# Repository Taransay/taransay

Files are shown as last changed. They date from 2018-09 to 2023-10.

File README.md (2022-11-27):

# Taransay home monitoring hardware and firmware
This is a series of wireless (433 MHz) electricity, gas, temperature and humidity monitors, electricity switches
and RGB(W) controllers and base station, with interoperability with [Home Assistant](https://www.home-assistant.io/). It uses low cost RF modules from HopeRF for intercommunication, avoiding the security
implications of having several seldomly-updated WiFi modules on your home network. The range is also
far greater.

The hardware and firmware designs are loosely based on those of the [emonTx](https://github.com/openenergymonitor/emontx3), [emonTH](https://github.com/openenergymonitor/emonth2) (both [OpenEnergyMonitor](http://openenergymonitor.com/)) and [Moteino](https://lowpowerlab.com/guide/moteino/) (LowPowerLab).

The firmware is designed to talk to Home Assistant via the Taransay base station, which is a small
transceiver that plugs into a Raspberry Pi or similar and talks to an instance of [Taransay
Data Forwarder](https://github.com/Taransay/taransayhub) over serial. This way, you just need to
keep your Raspberry Pi updated and not several distributed devices.

## Status
The hardware and firmware all works, though there are few instructions for getting it all to work,
so if you happen to want to use any of this it's best to get in touch.

## Credits
Sean Leavey <https://github.com/SeanDS>

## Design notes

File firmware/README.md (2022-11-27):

Taransay firmware
=================

Programming ATmega328P
----------------------

Using `avr-gcc` and `avrdude`. Alternative is to install Arduino IDE.

Requirements for Ubuntu:

```bash
sudo apt install gcc-avr binutils-avr gdb-avr avr-libc avrdude
```

Programmer might require special `udev` rules on Ubuntu. For instance, here is a `udev` entry for
the Atmel ICE, which should go in `/etc/udev/rules.d/99-atmelice.rules`:

```
SUBSYSTEM!="usb", ACTION!="add", GOTO="atmelice_end"

# Atmel Corp. Atmel ICE
ATTR{idVendor}=="03eb", ATTR{idProduct}=="2141", MODE="660", GROUP="dialout"

LABEL="atmelice_end"
```

After creating, restart `udev` with `sudo service udev restart`. Also ensure your user is part of
the `dialout` group.

Set fuses
---------

```
avrdude -p atmega328p -P usb -c atmelice_isp -U lfuse:w:0xff:m -U hfuse:w:0xd9:m -U efuse:w:0xff:m
```

Need to set those fuses otherwise weird serial outputs occur with characters etc.

Programming with ISP
--------------------

6-pin ISP header should be oriented with notch facing towards edge of board.

UART header mapping (starting from edge of board): GND, RX on board / TX on converter, TX on board /
RX on converter, DTR, 3V3

```
avrdude -p atmega328p -P usb -c atmelice_isp -U flash:w:taransay_X.ino.eightanaloginputs.hex
```

View device serial
------------------

```
minicom -b 115200 -D /dev/ttyUSB0
```

Writing messages to serial device
---------------------------------

```
echo -en 'hello\n' > /dev/ttyUSB0
```

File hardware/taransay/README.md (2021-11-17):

Taransay
========

Arduino-compatible RF transceiver board.

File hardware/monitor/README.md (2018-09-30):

Changes from emonTx V3.4 / emonTH V2.0
======================================

- Various component tweaks: different models, mainly
- Removed 3/4 current sensors
- Added Si7020/Si7021 temperature/humidity probe from emonTH V2
  - Reused ADC4 and ADC5 for SDA/SCL I2C bus to communicate with Si7020
  - Changed DS18B20 data pin from D5 to PC2 (ADC2) amd power pin from ADC5 to PC3 (ADC3)
- Removed ESP UART socket
- Explicitly implemented RFM69CW instead of (pin compatible) RFM12B
- Split pulse and temperature monitor ports into separate ports
  - Made PD4 the pulse power pin
- Changed pulse and temperature sockets from RJ45 to Molex Nano-Fit
- Removed AC-AC input
- Removed USB socket

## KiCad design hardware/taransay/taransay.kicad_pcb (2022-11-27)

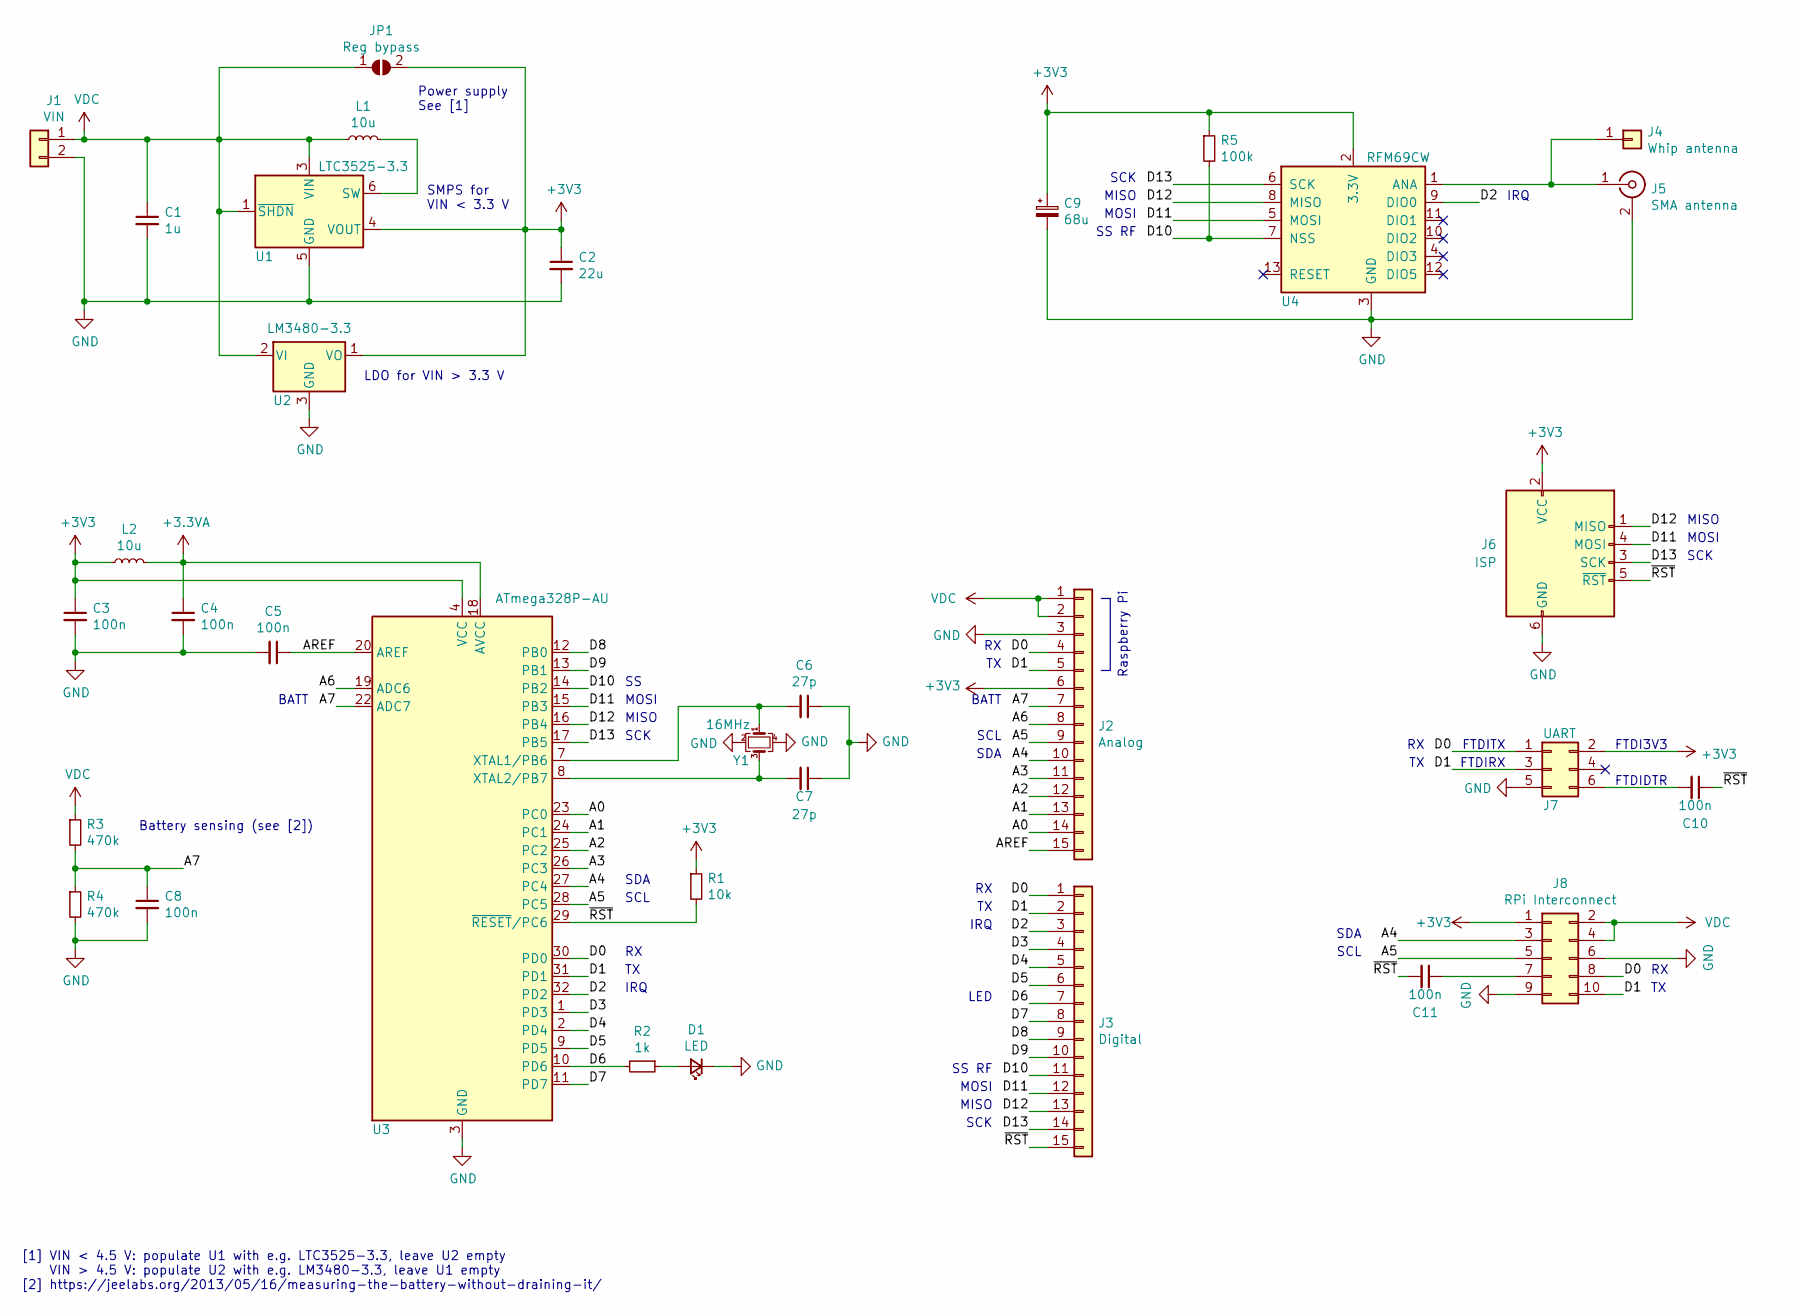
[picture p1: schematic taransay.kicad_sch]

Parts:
C1: 1u; C_0805_2012Metric; MPN1 C0805C105K4RACTU
C2: 22u; C_0805_2012Metric; MPN1 C0805C220J5GACTU
C3, C4, C5, C8, C10, C11: 100n; C_0805_2012Metric
C6, C7: 27p; C_0603_1608Metric
C9: 68u; CP_Radial_D6.3mm_P2.50mm
D1: LED; LED_0805_2012Metric_Pad1.15x1.40mm_HandSolder; MPN1 LG R971
J1: VIN; SolderWire-0.75sqmm_1x02_P4.8mm_D1.25mm_OD2.3mm
J2: Analog; PinSocket_1x15_P2.54mm_Vertical
J3: Digital; PinSocket_1x15_P2.54mm_Vertical
J4: Whip antenna; SolderWire-0.25sqmm_1x01_D0.65mm_OD1.7mm
J5: SMA antenna; SMA_Molex_73251-1153_EdgeMount_Horizontal; MPN1 73251-1150
J6: ISP; PinHeader_2x03_P2.54mm_Vertical; MPN1 251-8137
J7: UART; PinHeader_2x03_P2.54mm_Vertical; MPN1 251-8121
J8: RPi Interconnect; PinSocket_2x05_P2.54mm_Vertical; MPN1 215307-5
JP1: Reg bypass; SolderJumper-2_P1.3mm_Open_RoundedPad1.0x1.5mm
L1, L2: 10u; L_1210_3225Metric_Pad1.42x2.65mm_HandSolder; MPN1 LQH32CN100K53L
R1: 10k; R_0805_2012Metric
R2: 1k; R_0805_2012Metric
R3, R4: 470k; R_0805_2012Metric
R5: 100k; R_0805_2012Metric
U1: LTC3525-3.3; SOT-363_SC-70-6; MPN1 LTC3525ESC6-3.3#TRMPBF
U2: LM3480-3.3; SOT-23
U3: ATmega328P-AU; TQFP-32_7x7mm_P0.8mm
U4: RFM69CW; HOPERF_RFM69CW
Y1: 16MHz; Crystal_SMD_Abracon_ABM8G-4Pin_3.2x2.5mm; MPN1 ABM8-16.000MHZ-7-1-U-T

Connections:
+3.3VA: C4.1, L2.2, U3.18 (AVCC)
+3V3: C2.1, C3.1, C9.1, J2.6, J6.2 (VCC), J7.2, J8.1, JP1.2 (B), L2.1, R1.1, R5.1, U1.4 (VOUT), U2.1 (VO), U3.4 (VCC), U3.6 (VCC), U4.2 (3.3V)
/A0: J2.14, U3.23 (PC0)
/A1: J2.13, U3.24 (PC1)
/A2: J2.12, U3.25 (PC2)
/A3: J2.11, U3.26 (PC3)
/A4: J2.10, J8.3, U3.27 (PC4)
/A5: J2.9, J8.5, U3.28 (PC5)
/A6: J2.8, U3.19 (ADC6)
/A7: C8.1, J2.7, R3.2, R4.1, U3.22 (ADC7)
/AREF: C5.1, J2.15, U3.20 (AREF)
/D0: J2.4, J3.1, J7.1, J8.8, U3.30 (PD0)
/D1: J2.5, J3.2, J7.3, J8.10, U3.31 (PD1)
/D2: J3.3, U3.32 (PD2), U4.9 (DIO0)
/D3: J3.4, U3.1 (PD3)
/D4: J3.5, U3.2 (PD4)
/D5: J3.6, U3.9 (PD5)
/D6: J3.7, R2.2, U3.10 (PD6)
/D7: J3.8, U3.11 (PD7)
/D8: J3.9, U3.12 (PB0)
/D9: J3.10, U3.13 (PB1)
/D10: J3.11, R5.2, U3.14 (PB2), U4.7 (NSS)
/D11: J3.12, J6.4 (MOSI), U3.15 (PB3), U4.5 (MOSI)
/D12: J3.13, J6.1 (MISO), U3.16 (PB4), U4.8 (MISO)
/D13: J3.14, J6.3 (SCK), U3.17 (PB5), U4.6 (SCK)
/~RST: C10.1, C11.2, J3.15, J6.5 (~RST), R1.2, U3.29 (~RESET/PC6)
GND: C1.2, C2.2, C3.2, C4.2, C5.2, C6.1, C7.1, C8.2, C9.2, D1.1 (K), J1.2, J2.3, J5.2 (Ext), J6.6 (GND), J7.5, J8.6, J8.9, R4.2, U1.2 (GND), U1.5 (GND), U2.3 (GND), U3.3 (GND), U3.5 (GND), U3.21 (GND), U4.3 (GND), U4.14 (GND), Y1.2, Y1.4
unnamed: C6.2, U3.7 (XTAL1/PB6), Y1.1
unnamed: C7.2, U3.8 (XTAL2/PB7), Y1.3
unnamed: C10.2, J7.6
unnamed: C11.1, J8.7
unnamed: D1.2 (A), R2.1
unnamed: J4.1, J5.1 (In), U4.1 (ANA)
unnamed: L1.2, U1.6 (SW)
VDC: C1.1, J1.1, J2.1, J2.2, J8.2, J8.4, JP1.1 (A), L1.1, R3.1, U1.1 (~SHDN), U1.3 (VIN), U2.2 (VI)

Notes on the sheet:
LED
MISO
FTDI3V3
FTDIDTR
IRQ
SCL
SCK
MOSI
BATT
[1] VIN < 4.5 V: populate U1 with e.g. LTC3525-3.3, leave U2 empty VIN > 4.5 V: populate U2 with e.g. LM3480-3.3, leave U1 empty [2] https://jeelabs.org/2013/05/16/measuring-the-battery-without-draining-it/
SDA
LDO for VIN > 3.3 V
FTDITX
Battery sensing (see [2])
FTDIRX
SS RF
SMPS for VIN < 3.3 V
Power supply See [1]
Raspberry Pi

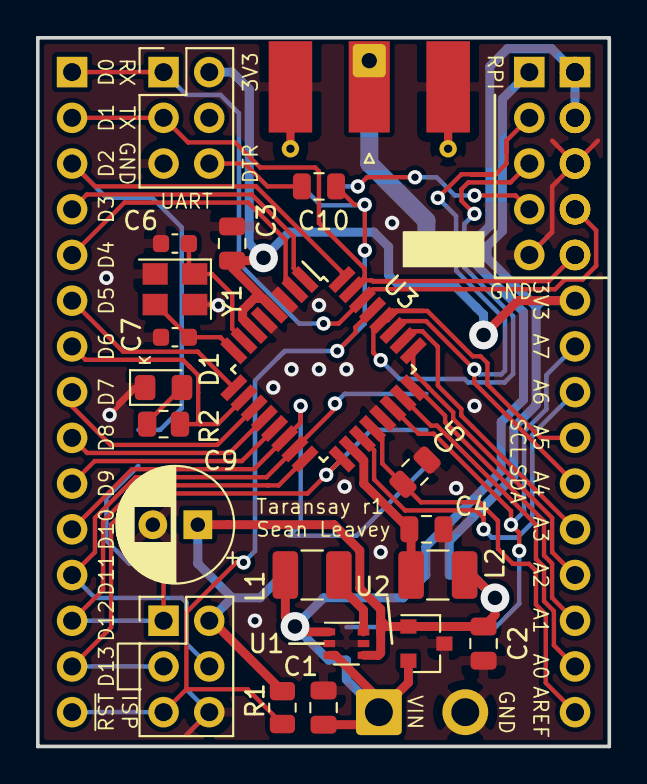
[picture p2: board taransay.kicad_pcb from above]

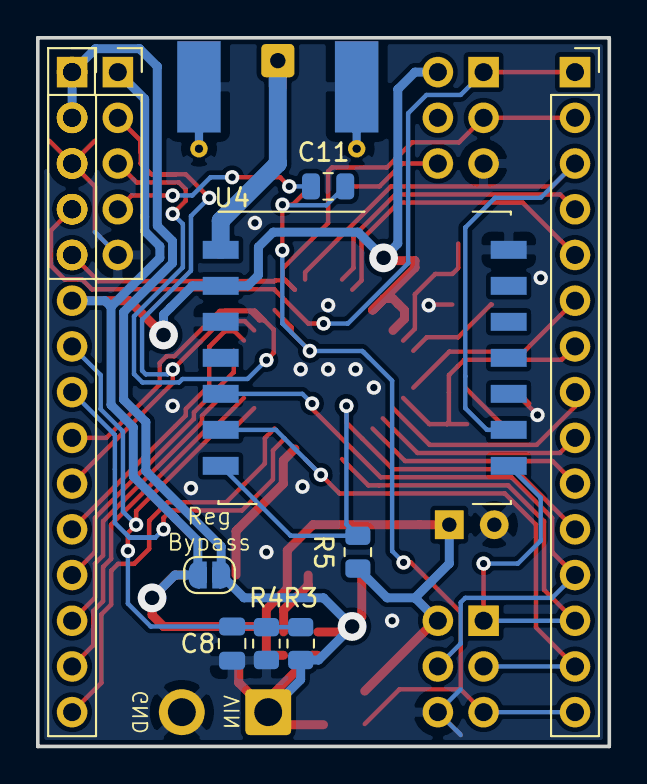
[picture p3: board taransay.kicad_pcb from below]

Board: 2 copper layers, 31.8 x 39.4 mm, 33 parts (10 on the bottom side), 35 nets.

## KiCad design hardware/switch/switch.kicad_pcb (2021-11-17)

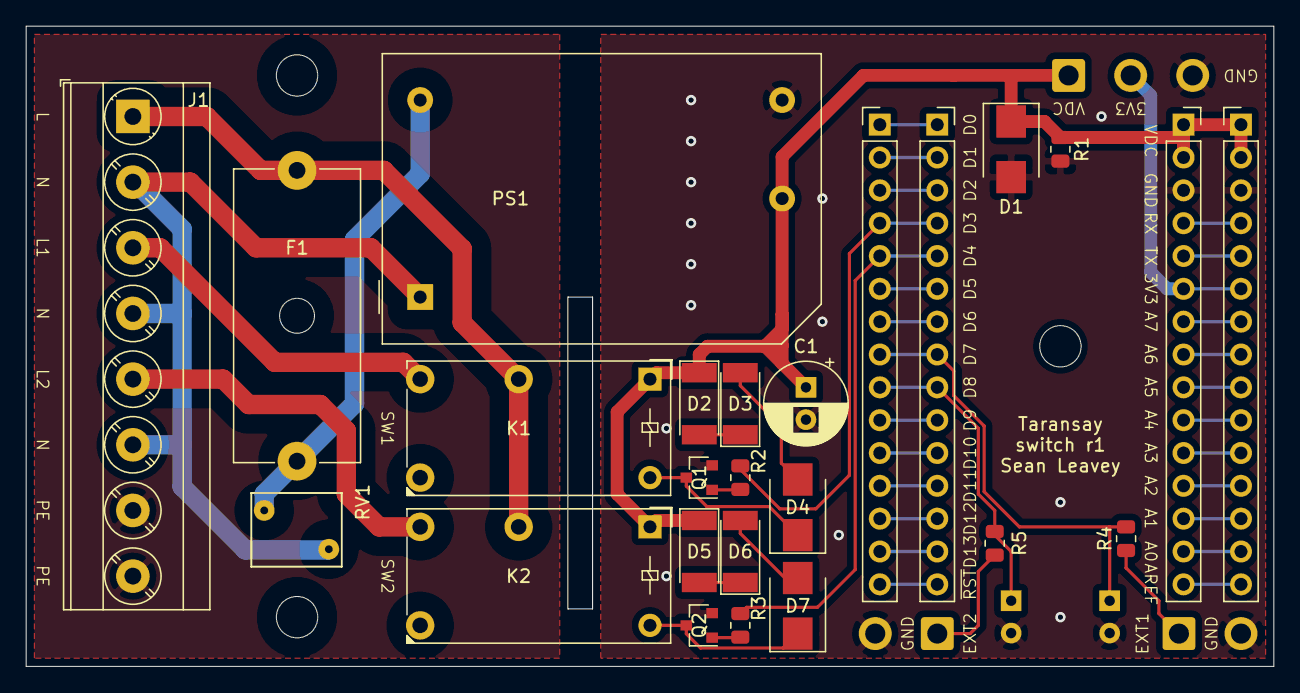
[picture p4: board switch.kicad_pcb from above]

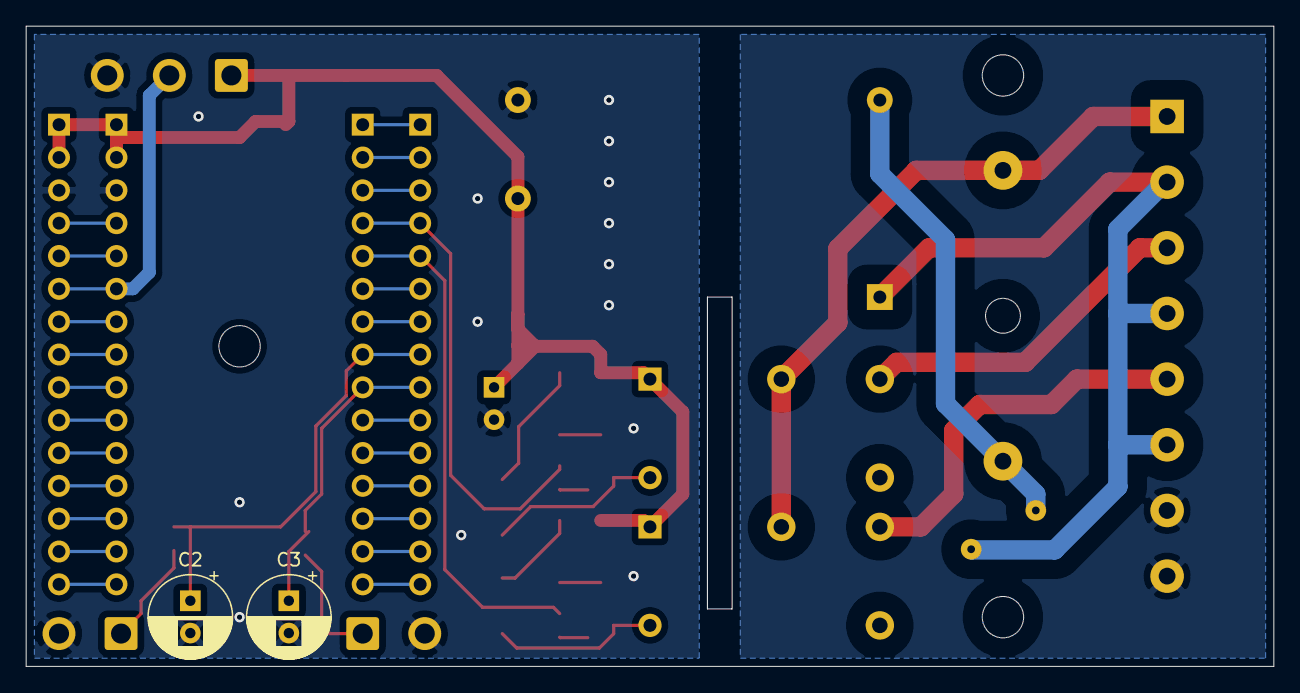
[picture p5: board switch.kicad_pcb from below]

Board: 2 copper layers, 96.5 x 49.5 mm, 33 parts (2 on the bottom side), 43 nets.

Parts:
C1, C2, C3: 68u; CP_Radial_D6.3mm_P2.50mm
D1, D4, D7: SMBJ7.0A; D_SMB
D2, D3, D5, D6: SM4007; D_MELF
F1: Fuse; Fuseholder_Cylinder-5x20mm_Schurter_0031_8201_Horizontal_Op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
H1, H2, H3: MountingHole; MountingHole_3.2mm_M3
J1: Power; TerminalBlock_Phoenix_MKDS-3-8-5.08_1x08_P5.08mm_Horizontal
J2: DC; SolderWire-0.75sqmm_1x03_P4.8mm_D1.25mm_OD2.3mm
J3: External button 1; SolderWire-0.75sqmm_1x02_P4.8mm_D1.25mm_OD2.3mm
J4: External button 2; SolderWire-0.75sqmm_1x02_P4.8mm_D1.25mm_OD2.3mm
J5: Analog; PinHeader_1x15_P2.54mm_Vertical
J6: Digital; PinHeader_1x15_P2.54mm_Vertical
J7: Analog breakout; PinSocket_1x15_P2.54mm_Vertical
J8: Digital breakout; PinSocket_1x15_P2.54mm_Vertical
K1, K2: FINDER-32.21-x000; Relay_SPDT_Finder_32.21-x000
PS1: RAC01-05SGB; Converter_ACDC_RECOM_RAC01-xxSGB_THT
Q1, Q2: MMBT2222AL; SOT-23
R1: NP; R_0805_2012Metric
R2, R3: 3k01; R_0805_2012Metric
R4, R5: 1k; R_0805_2012Metric
RV1: Varistor; RV_Disc_D7mm_W5.7mm_P5mm

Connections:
+3V3: J2.2, J5.6, J7.6
/A0: J5.14, J7.14
/A1: J5.13, J7.13
/A2: J5.12, J7.12
/A3: J5.11, J7.11
/A4: J5.10, J7.10
/A5: J5.9, J7.9
/A6: J5.8, J7.8
/A7: J5.7, J7.7
/AREF: J5.15, J7.15
/D0: J5.4, J6.1, J7.4, J8.1
/D1: J5.5, J6.2, J7.5, J8.2
/D2: J6.3, J8.3
/D3: J6.4, J8.4, R2.2
/D4: J6.5, J8.5, R3.2
/D5: J6.6, J8.6
/D6: J6.7, J8.7
/D7: C2.1, J6.8, J8.8, R4.2
/D8: C3.1, J6.9, J8.9, R5.2
/D9: J6.10, J8.10
/D10: J6.11, J8.11
/D11: J6.12, J8.12
/D12: J6.13, J8.13
/D13: J6.14, J8.14
/~RST: J6.15, J8.15
Earth_Protective: J1.7, J1.8
GND: C1.2, C2.2, C3.2, D1.2, J2.3, J3.2, J4.2, J5.3, J7.3, PS1.3, Q1.2, Q2.2, R1.2
unnamed: D2.2, D3.1
unnamed: D3.2, D4.2
unnamed: D4.1, K1.A2, Q1.3
unnamed: D5.2, D6.1
unnamed: D6.2, D7.2
unnamed: D7.1, K2.A2, Q2.3
unnamed: F1.1, PS1.2, RV1.1
unnamed: F1.2, J1.1, K1.11, K2.11
unnamed: J1.2, J1.4, J1.6, PS1.1, RV1.2
unnamed: J1.3, K1.14
unnamed: J1.5, K2.14
unnamed: J3.1, R4.1
unnamed: J4.1, R5.1
unnamed: Q1.1, R2.1
unnamed: Q2.1, R3.1
VDC: C1.1, D1.1, D2.1, D5.1, J2.1, J5.1, J5.2, J7.1, J7.2, K1.A1, K2.A1, PS1.4, R1.1

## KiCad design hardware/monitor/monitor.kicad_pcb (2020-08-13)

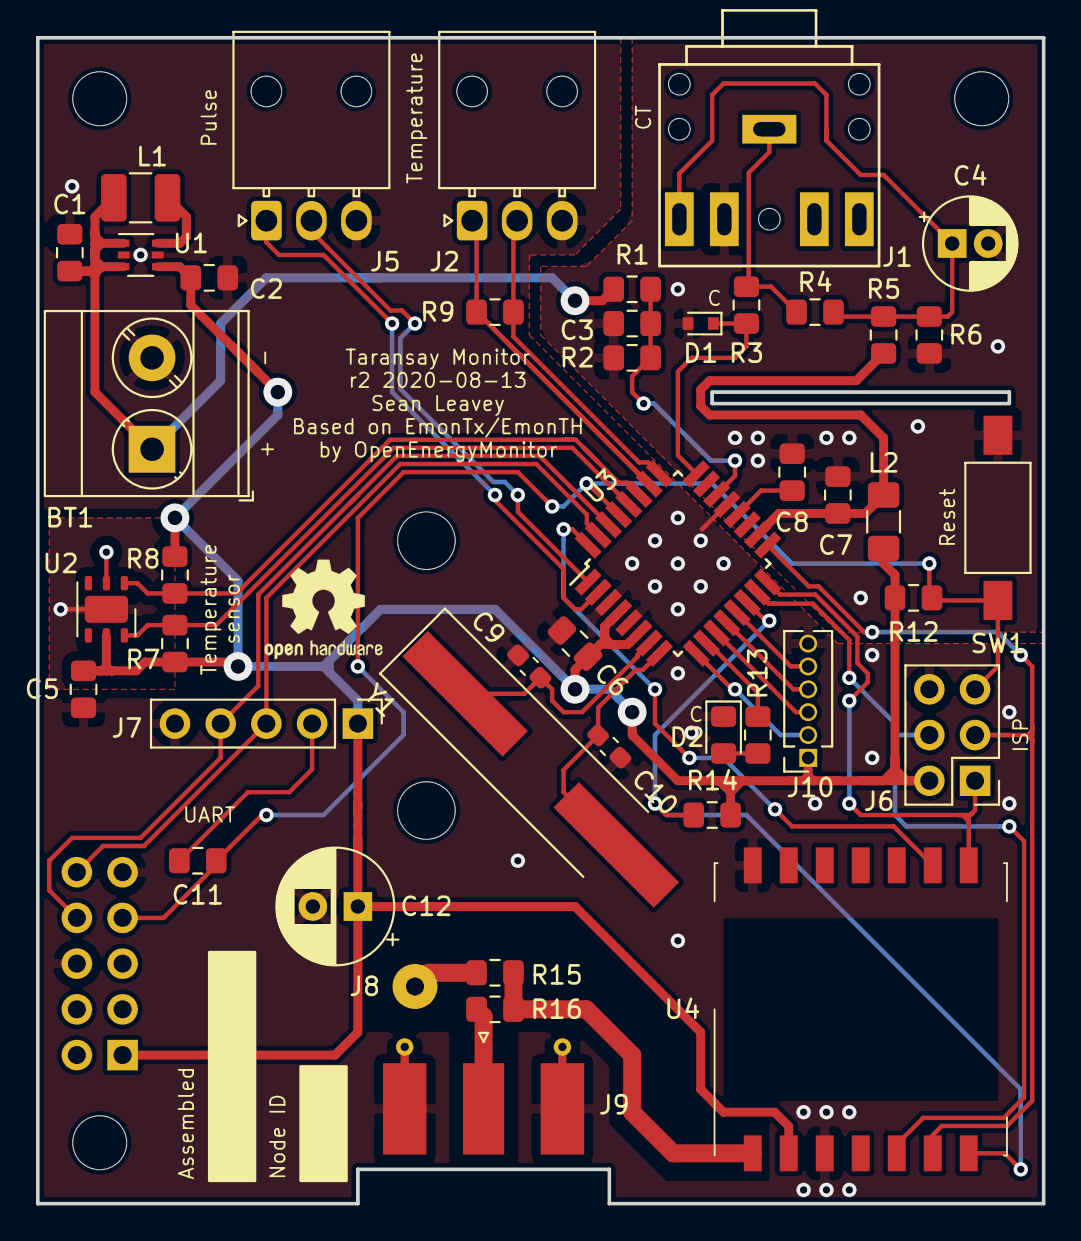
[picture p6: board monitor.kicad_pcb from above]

Board: 2 copper layers, 55.9 x 64.8 mm, 52 parts (1 on the bottom side), 36 nets.

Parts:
BT1: Battery; TerminalBlock_Phoenix_MKDS-3-2-5.08_1x02_P5.08mm_Horizontal
C1: 1u; C_0805_2012Metric_Pad1.15x1.40mm_HandSolder
C2: 22u; C_0805_2012Metric_Pad1.15x1.40mm_HandSolder
C3: NP; C_0805_2012Metric_Pad1.15x1.40mm_HandSolder
C4: 10u; CP_Radial_D5.0mm_P2.00mm
C5, C6, C7, C8, C11: 100n; C_0805_2012Metric_Pad1.15x1.40mm_HandSolder
C9, C10: 26p; C_0603_1608Metric_Pad1.05x0.95mm_HandSolder
C12: 68u; CP_Radial_D6.3mm_P2.50mm
D1: ESD5Z3.3T1G; D_SOD-523
D2: LED; LED_0805_2012Metric_Pad1.15x1.40mm_HandSolder
H1: Mount 1; MountingHole_3mm
H2: Mount 2; MountingHole_3mm
H3: Mount 3; MountingHole_3mm
H5: Battery Mount 1; MountingHole_3.2mm_M3
H6: Battery Mount 2; MountingHole_3.2mm_M3
J1: CT; StereoJack_3.5mm_Switch_Cliff_JY039-5P_Horizontal
J2: T1; Molex_Nano-Fit_105313-xx03_1x03_P2.50mm_Horizontal
J3: RPi Interconnect; PinSocket_2x05_P2.54mm_Vertical
J5: Pulse; Molex_Nano-Fit_105313-xx03_1x03_P2.50mm_Horizontal
J6: ISP; PinHeader_2x03_P2.54mm_Vertical
J7: UART; PinHeader_1x05_P2.54mm_Vertical
J8: Whip antenna; SolderWirePad_1x01_Drill1mm
J9: SMA antenna; SMA_Molex_73251-1153_EdgeMount_Horizontal
J10: Spare; PinSocket_1x06_P1.27mm_Vertical
L1: 10u; L_1210_3225Metric_Pad1.42x2.65mm_HandSolder
L2: 10u; L_1206_3216Metric_Pad1.42x1.75mm_HandSolder
LOGO1: Logo; OSHW-Logo2_7.3x6mm_SilkScreen
R1, R2: 470k; R_0805_2012Metric_Pad1.15x1.40mm_HandSolder
R3, R13: 1k; R_0805_2012Metric_Pad1.15x1.40mm_HandSolder
R4: 22R/0.1%; R_0805_2012Metric_Pad1.15x1.40mm_HandSolder
R5, R6: 470k/0.1%; R_0805_2012Metric_Pad1.15x1.40mm_HandSolder
R7, R8, R9: 4k7; R_0805_2012Metric_Pad1.15x1.40mm_HandSolder
R12: 10k; R_0805_2012Metric_Pad1.15x1.40mm_HandSolder
R14: 100k; R_0805_2012Metric_Pad1.15x1.40mm_HandSolder
R15, R16: 0R; R_0805_2012Metric_Pad1.15x1.40mm_HandSolder
SW1: Reset; SW_SPST_FSMSM
U1: LTC3525-3.3; SOT-363_SC-70-6
U2: Si7020-A20; DFN-6-1EP_3x3mm_P1mm_EP1.5x2.4mm
U3: ATmega328P-AU; TQFP-32_7x7mm_P0.8mm
U4: RFM69CW; HOPERF_RFM69CW
Y1: 16MHz; Crystal_SMD_HC49-SD_HandSoldering

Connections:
+3.3VA: C7.1, L2.1, R5.1, U3.18
+3V3: C2.1, C5.1, C6.1, C12.1, J3.1, J6.2, J7.1, J10.1, L2.2, R7.1, R8.1, R12.1, R14.1, U1.4, U2.5, U3.4, U3.6, U4.2
+BATT: BT1.1, C1.1, L1.1, R1.1, U1.1, U1.3
/Microcontroller/BATT_MON: C3.1, R1.2, R2.1, U3.22
/Microcontroller/CT_SIGNAL: D1.1, R3.1, U3.24
/Microcontroller/D5: J10.2, U3.9
/Microcontroller/D7: J10.3, U3.11
/Microcontroller/D8: J10.4, U3.12
/Microcontroller/D9: J10.5, U3.13
/Microcontroller/DS_POWER: J2.1, R9.1, U3.26
/Microcontroller/DS_SIGNAL: J2.2, R9.2, U3.25
/Microcontroller/MISO: J6.1, U3.16, U4.8
/Microcontroller/MOSI: J6.4, U3.15, U4.5
/Microcontroller/PULSE_IRQ: J5.2, U3.1
/Microcontroller/PULSE_POWER: J5.1, U3.2
/Microcontroller/RF_IRQ: U3.32, U4.9
/Microcontroller/RF_SS: R14.2, U3.14, U4.7
/Microcontroller/RX: J3.8, J7.4, U3.30
/Microcontroller/Reset: C11.2, J3.7, J6.5, R12.2, SW1.1, U3.29
/Microcontroller/SCK: J6.3, U3.17, U4.6
/Microcontroller/SCL: R7.2, U2.6, U3.28
/Microcontroller/SDA: R8.2, U2.1, U3.27
/Microcontroller/TX: J3.10, J7.3, U3.31
GND: BT1.2, C1.2, C2.2, C3.2, C4.2, C5.2, C6.2, C7.2, C8.2, C9.1, C10.1, C12.2, D1.2, D2.1, J1.4, J2.3, J3.6, J3.9, J5.3, J6.6, J7.5, J9.2, J10.6, R2.2, R6.2, SW1.2, U1.2, U1.5, U2.2, U3.3, U3.5, U3.21, U4.3, U4.14
unnamed: C4.1, J1.5, R4.2, R5.2, R6.1
unnamed: C8.1, U3.20
unnamed: C9.2, U3.7, Y1.1
unnamed: C10.2, U3.8, Y1.2
unnamed: C11.1, J7.2
unnamed: D2.2, R13.1
unnamed: J1.1, R3.2, R4.1
unnamed: J8.1, R15.1
unnamed: J9.1, R16.1
unnamed: L1.2, U1.6
unnamed: R13.2, U3.10
unnamed: R15.2, R16.2, U4.1

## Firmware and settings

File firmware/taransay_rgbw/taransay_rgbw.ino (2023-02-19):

// Taransay RGBW
//
// For SK6812 RGBW LEDs (e.g. Neopixel).
// Based on Adafruit Neopixel RGBWstrandtest example.
//
// Sean Leavey <electronics@attackllama.com>

#define FIRMWARE_VERSION "1.1.0"

// RFM69CW settings.
#define RF69_SPI_CS         10
#define RF69_IRQ_PIN        2
#define FREQUENCY           RF69_433MHZ
#define NODE_ID             6
#define BASE_ID             1
#define NETWORK_ID          1
#define MAX_BUFFER_LENGTH   61                   // Limited by RFM69 library.
//#define ENABLE_ATC                             // Enable auto transmission control.

// LED strip settings.
#define LED_PIN             6
#define LED_COUNT           160
#define BRIGHTNESS          255
#define FOOTSWITCH_PIN A7

#include <avr/pgmspace.h>
#include <Taransay.h>
#include <Adafruit_NeoPixel.h>

Adafruit_NeoPixel strip = Adafruit_NeoPixel(LED_COUNT, LED_PIN, NEO_GRBW + NEO_KHZ800);

const uint8_t PROGMEM gamma8[] = {
    0,   0,   0,   0,   0,   0,   0,   0,   0,   0,   0,   0,   0,   0,   0,   0,
    0,   0,   0,   0,   0,   0,   0,   0,   0,   0,   0,   0,   1,   1,   1,   1,
    1,   1,   1,   1,   1,   1,   1,   1,   1,   2,   2,   2,   2,   2,   2,   2,
    2,   3,   3,   3,   3,   3,   3,   3,   4,   4,   4,   4,   4,   5,   5,   5,
    5,   6,   6,   6,   6,   7,   7,   7,   7,   8,   8,   8,   9,   9,   9,  10,
   10,  10,  11,  11,  11,  12,  12,  13,  13,  13,  14,  14,  15,  15,  16,  16,
   17,  17,  18,  18,  19,  19,  20,  20,  21,  21,  22,  22,  23,  24,  24,  25,
   25,  26,  27,  27,  28,  29,  29,  30,  31,  32,  32,  33,  34,  35,  35,  36,
   37,  38,  39,  39,  40,  41,  42,  43,  44,  45,  46,  47,  48,  49,  50,  50,
   51,  52,  54,  55,  56,  57,  58,  59,  60,  61,  62,  63,  64,  66,  67,  68,
   69,  70,  72,  73,  74,  75,  77,  78,  79,  81,  82,  83,  85,  86,  87,  89,
   90,  92,  93,  95,  96,  98,  99, 101, 102, 104, 105, 107, 109, 110, 112, 114,
  115, 117, 119, 120, 122, 124, 126, 127, 129, 131, 133, 135, 137, 138, 140, 142,
  144, 146, 148, 150, 152, 154, 156, 158, 160, 162, 164, 167, 169, 171, 173, 175,
  177, 180, 182, 184, 186, 189, 191, 193, 196, 198, 200, 203, 205, 208, 210, 213,
  215, 218, 220, 223, 225, 228, 231, 233, 236, 239, 241, 244, 247, 249, 252, 255
};

// Command handling.
static uint16_t rf_dest;
static char rf_in_buf[MAX_BUFFER_LENGTH];
static char rf_out_buf[MAX_BUFFER_LENGTH];
static uint8_t rf_in_len;
static uint8_t rf_out_len;
static bool rf_ack;
static uint8_t rf_retries = 3;

// State.
typedef struct {
  bool on = false;
  uint8_t red = 0;
  uint8_t green = 0;
  uint8_t blue = 0;
  uint8_t white = 255;
} State;

State state;
bool update_strip = false;
bool report_state = false;

// Button debouncing.
bool button_triggered = false;

#ifdef ENABLE_ATC
  RFM69_ATC radio;
#else
  RFM69 radio;
#endif

static void print_help() {
  Serial.println(
    F(
      "; Available commands:\r\n"
      ";  STATE:<state>[:RGBW:<r>,<g>,<b>,<w>] - set state to <state> and RGBW to <r>, <g>, <b>, <w>\r\n"
      ";  NACK:<n>                             - set number of ACK retries to <n>\r\n"
      ";  HELP                                 - print this help"
    )
  );
}

static void handle_serial() {
  static char input_line[MAX_BUFFER_LENGTH];
  static uint8_t input_pos = 0;
  char c = Serial.read();

  switch (c) {
    case '\r':  // Ignore carriage return.
      break;

    case '\n':
      if (!input_pos) {
        // Ignore empty lines.
        break;
      }

      input_line[input_pos] = '\0';  // Null terminate the string.
      parse_command(input_line);
      input_pos = 0;
      break;

    default:
      // Add the character to the line if it's not yet full, otherwise discard.
      if (input_pos < (MAX_BUFFER_LENGTH - 1)) {
        input_line[input_pos++] = c;
      }

      break;
  }
}

static void handle_rf_payload() {
  rf_in_buf[rf_in_len] = '\0';
  parse_command(rf_in_buf);
  rf_in_len = 0;
}

static void parse_command(char message[]) {
  char *token;

  // Begin parse.
  token = strtok(message, ":");
  Serial.print(F("> "));
  Serial.print(token);

  if (strcmp(token, "HELP") == 0) {
    Serial.println();
    print_help();

    // Successful parse.
    return;
  } else if (strcmp(token, "STATE") == 0) {
    // Set state.
    rf_ack = true;

    Serial.print(F(" "));
    token = strtok(null, ":");  // state
    Serial.print(token);
    state.on = strcmp(token, "ON") == 0;

    Serial.print(F(" "));
    token = strtok(null, ":");
    Serial.print(token);

    if (strcmp(token, "RGBW") == 0) {
      Serial.print(F(" "));
      token = strtok(null, ",");  // R
      Serial.print(token);
      state.red = atoi(token);

      Serial.print(F(","));
      token = strtok(null, ",");  // G
      Serial.print(token);
      state.green = atoi(token);

      Serial.print(F(","));
      token = strtok(null, ",");  // B
      Serial.print(token);
      state.blue = atoi(token);

      Serial.print(F(","));
      token = strtok(null, ",");  // W
      Serial.print(token);
      state.white = atoi(token);
    }

    Serial.println();

    update_strip = true;
    report_state = true;

    // Successful parse.
    return;
  } else if (strcmp(token, "NACK") == 0) {
    Serial.print(F(" "));
    token = strtok(null, ":");
    rf_retries = atoi(token);
    Serial.println(token);

    if (rf_retries > 0) {
      Serial.print(F("number of ACK retries set to "));
      Serial.println(rf_retries);
    } else {
      Serial.println(F("! number of ACK retries must be > 0"));
    }

    // Successful parse.
    return;
  }

  Serial.println();
  Serial.print(F("; unrecognised command '"));
  Serial.print(token);
  Serial.println(F("'"));
}

void setup() {
  hardware_init();

  // Set external switch to tristate.
  pinMode(FOOTSWITCH_PIN, INPUT_PULLUP);

  Serial.print(F("; Taransay RGB v"));
  Serial.println(FIRMWARE_VERSION);
  Serial.println(F("; Sean Leavey <electronics@attackllama.com>"));

  delay(500);
  print_sensor_status();

  radio.initialize(FREQUENCY, NODE_ID, NETWORK_ID);

  Serial.println(F("; RFM69CW enabled: "));
  Serial.print(F(";   frequency: "));
  Serial.println(FREQUENCY == RF69_433MHZ ? "433" : FREQUENCY == RF69_868MHZ ? "868" : "915");
  Serial.print(F(";   node: "));
  Serial.println(NODE_ID);
  Serial.print(F(";   network: "));
  Serial.println(NETWORK_ID);
#ifdef ENABLE_ATC
  Serial.println(F(";   auto transmission control enabled"));
#endif

  // Disable unused pins, buses, etc.
  //hardware_disable();

  strip.begin();
  strip.show();  // Update LED contents. To start with, they are all set to off.
  strip.setBrightness(BRIGHTNESS);

  report_state = true;

  Serial.println();
  print_help();
}

void loop() {
  if (Serial.available()) {
    handle_serial();
  }

  if (report_state && radio.canSend()) {
    static char rstr[4];
    static char gstr[4];
    static char bstr[4];
    static char wstr[4];

    rf_dest = BASE_ID;
    rf_out_buf[0] = '\0';
    strcat(rf_out_buf, "STATE:");
    if (state.on) {
      strcat(rf_out_buf, "ON");

      itoa(state.red, rstr, 10);
      itoa(state.green, gstr, 10);
      itoa(state.blue, bstr, 10);
      itoa(state.white, wstr, 10);

      strcat(rf_out_buf, ":RGBW:");
      strcat(rf_out_buf, rstr);
      strcat(rf_out_buf, ",");
      strcat(rf_out_buf, gstr);
      strcat(rf_out_buf, ",");
      strcat(rf_out_buf, bstr);
      strcat(rf_out_buf, ",");
      strcat(rf_out_buf, wstr);
    } else {
      strcat(rf_out_buf, "OFF");
    }
    rf_out_len = strlen(rf_out_buf);

    Serial.print(F("send ["));
    Serial.print(rf_dest);
    Serial.print(F("] "));

    for (uint8_t i = 0; i < rf_out_len; i++) {
      Serial.print(rf_out_buf[i]);
    }

    if (rf_ack) {
      if (radio.sendWithRetry(rf_dest, rf_out_buf, rf_out_len, rf_retries)) {
        Serial.print(F(" [ACK success]"));
      } else {
        Serial.print(F(" [ACK failure]"));
      }
    } else {
      radio.send(rf_dest, rf_out_buf, rf_out_len);
    }

    Serial.println();
    rf_dest = 0;
    report_state = false;
  }

  if (radio.receiveDone()) {
    int16_t rssi = radio.RSSI;  // Copy as soon as possible after receive.
    bool ack_requested = radio.ACKRequested();

    // Copy received payload.
    memcpy(rf_in_buf, radio.DATA, radio.DATALEN);
    rf_in_len = radio.DATALEN;

    if (ack_requested) {
      radio.sendACK();
    }

    Serial.print(F("receive "));
    Serial.print(F("[from "));
    Serial.print(radio.SENDERID);
    Serial.print(F("] "));

    for (uint8_t i = 0; i < rf_in_len; i++) {
      if (rf_in_buf[i] == '\n' || rf_in_buf[i] == '\r') {
        // Remove newlines in the payload. This should only ever happen with
        // noisy data that actually made it through.
        rf_in_buf[i] = ' ';
      }

      Serial.print((char) rf_in_buf[i]);
    }

    Serial.print(F(" [RSSI "));
    Serial.print(rssi);
    Serial.print(F("]"));

    if (ack_requested) {
      Serial.print(F(" [ACK]"));
    }

    Serial.println();
    handle_rf_payload();
  }

  bool button = analogRead(FOOTSWITCH_PIN) > 800;  // For some reason digitalRead doesn't detect LOW properly.
  if (button_triggered && button) {
    // Fired button transitioned back to HIGH.
    bool was_on = state.on;
    state = State();
    state.on = !was_on;
    update_strip = true;
    report_state = true;

    button_triggered = false;
  } else {
    if (!button) {
      // Initial firing. Button is LOW.
      button_triggered = true;
    }
  }

  if (update_strip) {
    update_rgb();
    strip.show();
    update_strip = false;
  }
}

uint8_t gamma(uint8_t value) {
  return pgm_read_byte(&gamma8[value]);
}

void update_rgb() {
  uint8_t red;
  uint8_t green;
  uint8_t blue;
  uint8_t white;

  if (state.on) {
    // Apply gamma correction.
    red = gamma(state.red);
    green = gamma(state.green);
    blue = gamma(state.blue);
    white = gamma(state.white);
  } else {
    red = 0;
    green = 0;
    blue = 0;
    white = 0;
  }

  for (uint8_t i = 0; i < strip.numPixels(); i++) {
    strip.setPixelColor(i, red, green, blue, white);
  }
}

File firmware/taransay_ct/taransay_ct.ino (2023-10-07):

#define FIRMWARE_VERSION "1.2.0"

extern const int VOLTAGE_RMS = 230;
extern const int VOLTAGE_SAMPLES = 1662;
// Current calibration: (2000 turns / 22 ohm burden resistance).
extern const int CURRENT_CALIBRATION = 90.9;

// Set DS18B20 temperature precision. The higher the precision, the longer, and therefore
// more battery power, the conversion takes.
// 9 (93.8ms), 10 (187.5ms), 11 (375ms) or 12 (750ms) bits
// equal to resolution of 0.5 C, 0.25 C, 0.125 C and 0.0625 C.
#define DS18B20_PRECISION     11
#define ASYNC_DELAY           375

// RFM69CW settings.
#define RF69_SPI_CS         10
#define RF69_IRQ_PIN        2
#define FREQUENCY           RF69_433MHZ
#define NODE_ID             10
#define BASE_ID             1
#define NETWORK_ID          1
#define MAX_BUFFER_LENGTH   61                   // Limited by RFM69 library.
#define ENABLE_ATC                               // Enable auto transmission control.

#include <avr/power.h>
#include <avr/pgmspace.h>
#include <LowPower.h>
#include <Taransay.h>
#include <EmonLib.h>

// Watchdog timeout.
#define WDT_PERIOD            SLEEP_8S
// State updated after WDT_MAX_NUMBER periods of WDT_PERIOD.
#define WDT_MAX_NUMBER        2  // approx. 16 seconds

// Watchdog timer count.
uint16_t WDT_number = 0;

// Command handling.
static uint16_t rf_dest;
static char rf_out_buf[MAX_BUFFER_LENGTH];
static uint8_t rf_out_len;
static bool rf_ack = true;
static uint8_t rf_retries = 3;

// State structure.
typedef struct {
  int16_t supply_voltage;               // x1000
  int16_t power;                        // x1
  int16_t temperature;                  // x10
  int16_t ext_temperature;              // x10
  int16_t humidity;                     // x10
} State;

State state;
bool report_state;

#ifdef ENABLE_ATC
  RFM69_ATC radio;
#else
  RFM69 radio;
#endif

void setup() {
  hardware_init();

  Serial.print(F("; Taransay CT v"));
  Serial.println(FIRMWARE_VERSION);
  Serial.println(F("; Sean Leavey <electronics@attackllama.com>"));

  delay(500);
  print_sensor_status();

  radio.initialize(FREQUENCY, NODE_ID, NETWORK_ID);

  Serial.println(F("; RFM69CW enabled: "));
  Serial.print(F(";   frequency: "));
  Serial.println(FREQUENCY == RF69_433MHZ ? "433" : FREQUENCY == RF69_868MHZ ? "868" : "915");
  Serial.print(F(";   node: "));
  Serial.println(NODE_ID);
  Serial.print(F(";   network: "));
  Serial.println(NETWORK_ID);
#ifdef ENABLE_ATC
  Serial.println(F(";   auto transmission control enabled"));
#endif

  // Disable unused pins, buses, etc.
  hardware_disable();

  // Let sensors settle then make a measurement.
  delay(2000);
  report_state = true;
}

void loop() {
  if (report_state) {
    static char vstr[6];
    static char pstr[6];
    static char t1str[6];
    static char t2str[6];
    static char hstr[6];

    // Get supply voltage.
    if (battery_enabled) {
      battery_read();
    } else {
      battery_voltage = 0;
    }

    state.supply_voltage = battery_voltage;

    // Read power.
    if (ct_enabled) {
      ct_read();
    } else {
      // Set power to zero.
      ct_power = 0;
    }

    state.power = ct_power;

    // Read from SI7021 temperature and humidity sensor.
    if (si7021_enabled) {
      si7021_read();
      state.temperature = si7021_temperature;
      state.humidity = si7021_humidity;
    }

    // Get external temperature reading.
    if (ds18b20_enabled) {
      ds18b20_read();
    }

    // Copy temperature into payload.
    state.ext_temperature = ds18b20_temperature;

    ////////////////
    // Send data. //
    ////////////////

    rf_dest = BASE_ID;
    rf_out_buf[0] = '\0';

    strcat(rf_out_buf, "STATE:");

    itoa(state.supply_voltage, vstr, 10);
    itoa(state.power, pstr, 10);
    itoa(state.temperature, t1str, 10);
    itoa(state.ext_temperature, t2str, 10);
    itoa(state.humidity, hstr, 10);

    strcat(rf_out_buf, "V:");
    strcat(rf_out_buf, vstr);
    strcat(rf_out_buf, ":P:");
    strcat(rf_out_buf, pstr);
    strcat(rf_out_buf, ":T1:");
    strcat(rf_out_buf, t1str);
    strcat(rf_out_buf, ":T2:");
    strcat(rf_out_buf, t2str);
    strcat(rf_out_buf, ":H:");
    strcat(rf_out_buf, hstr);

    rf_out_len = strlen(rf_out_buf);

    Serial.print(F("send ["));
    Serial.print(rf_dest);
    Serial.print(F("] "));

    for (uint8_t i = 0; i < rf_out_len; i++) {
      Serial.print(rf_out_buf[i]);
    }

    if (rf_ack) {
      if (radio.sendWithRetry(rf_dest, rf_out_buf, rf_out_len, rf_retries)) {
        Serial.print(F(" [ACK success]"));
      } else {
        Serial.print(F(" [ACK failure]"));
      }
    } else {
      radio.send(rf_dest, rf_out_buf, rf_out_len);
    }

    Serial.println();
    rf_dest = 0;
    report_state = false;

    delay(100);  // Allow message to send before sleeping.
    radio.sleep();
  }

  LowPower.idle(
    WDT_PERIOD,
    ADC_OFF,
    TIMER2_OFF,
    TIMER1_OFF,
    TIMER0_OFF,
    SPI_OFF,
    USART0_OFF,
    TWI_OFF
  );

  WDT_number++;

  if (WDT_number < WDT_MAX_NUMBER) {
    return;
  }

  // Reset watchdog count.
  WDT_number = 0;

  report_state = true;
}

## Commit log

2018-09-30 Add r1 hardware
    [microcontroller.sch, monitor.kicad_pcb, monitor.sch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]
2018-11-12 Add current transducer support
2018-11-12 Fix temperature readout
2018-11-12 Set default temperature when sensor not detected
2018-11-17 Fix battery monitor code
    [taransay_base.ino, taransay_ct.ino]
2019-02-19 Add temperature/humidity node firmware
2019-08-16 Version with CurrentTransformer library (https://github.com/JChristensen/CurrentTransformer)
2019-08-16 reverted to use emonTx CT code
    [taransay_ct.ino]
2020-08-13 Hardware revision 2
    [monitor.kicad_pcb]
2021-11-17 Move Taransay Monitor to subdirectory; add BOM
    [microcontroller.sch, monitor.kicad_pcb, monitor.sch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]
2021-11-17 Add Taransay transceiver
    [taransay.kicad_pcb, taransay.sch]
2021-11-17 Add Taransay switch
    [switch.kicad_pcb, switch.sch]
2021-11-17 Remove JLCPCB silkscreen text
    [switch.kicad_pcb]
2021-11-17 Fix capacitor value
    [taransay.sch]
2022-04-30 Taransay RGBW firmware and schematic as used for large matchstick light
    [taransay.kicad_sch]
2022-11-02 Replace LED library with FastLED, which allows dithering to achieve lower brightnesses
    [taransay_rgb.ino]
2022-11-27 Clean up unused files
    [taransay.kicad_sch]
2022-11-27 Update switch hardware
    [switch.kicad_sch, switch.sch]
2022-11-27 Update Taransay board to Kicad 6
    [taransay.kicad_pcb, taransay.kicad_sch, taransay.sch]
2023-02-19 Fix RGBW on/off via HomeAssistant app bug
    [taransay_rgbw.ino]
2023-10-07 Update KiCad project files to v7
